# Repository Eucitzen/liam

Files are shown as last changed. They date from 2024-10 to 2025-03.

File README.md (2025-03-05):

# liam - DIY Robot lawn mower

Updates by Eu_citzen 2024-10-10 In development:
- Working (BETA) on a stuck detection function using MPU9150
- Obsticle avoidance using 3 ultrasonic sensors
- Merging several libraries into distinct categories
- Due to increased pin requirements it's being geared towards an STM32 Blackpill module instead of the usual Arduino Uno

Liam is an arduino project for the DIY Robot Lawn Mover.
This program will control your mower and relies on a two coil
configuration (0 and 1) with an optional (2).

The mower is assumed to be rear wheel driven and have three
boundary wire reciever coils in the following configuration

    wheel
    ----------------
    |           (0)|
    |(2)           |  ----> Mowing direction
    |           (1)|
    ----------------
    wheel

Licensed under GNU GPL 3.0

(c) 2017 Jonas Forssell & team

Configuration
------
Most of the default values for your mower can be set in the
Definition.h file. Use this to configure your mower for best
performance.

Configurations can also be put in a file called
`LocalDefinition.h`, which will override `Definition.h` but
is not tracked by git. This might be useful if you like to
stay on top of any code updates, but don't want to remake
the same configuration changes all the time.

Compile
------
The following libraries must be added to your arduino IDE to be able to compile the source

  * HMC5883L
  * I2Cdev
  * LiquidCrystal_I2C
  * MPU9150
  * RTClib
  * RTIMULib

  The libraries you need are bundled with the liam code within each release.

Change log
------
Change log
------
2025-03:
- Further cleaning up library code
- Started working on PCB using STM32F407VET6TR & ESP32 module

2024-12:
- Remade the libraries into relevant categories (e.g. "sensors", "display", "motioncontrol")
- Started removing superflourous libraries for newer Arduino versions
- Cleaning up code for STM32 microcontrollers, found even the STM32 Blackpill has too few pins

2024-11:
- Remade to suite a STM32 Blackpill board, new version needs more pins
- Merged several libraries into distinct categories
- Beta stuck detection using MPU9150
- Added and test printed 3D models for a larger mower

Links
------

[Wiki - work in progress](https://github.com/sm6yvr/liam/wiki)

[Facebook group DIY Robot Lawn Mower](https://www.facebook.com/groups/319588508137220/)

[Build instructions Trello](https://trello.com/b/gYQjoWY5/liam)

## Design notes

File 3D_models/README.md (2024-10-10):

This 3D model is still at a concept stage and is designed around a printer with a 250x250 sized bed.
In other words; the model is intended to be split into 4 equally sized sections.

And "reinforcement_parts.stl" acts as a screw-together support using M4 bolts. Pro tip: use some kind of adhesive, watertight glue inderneat the reinforcement parts!

Note that it works on a 3 wheel basis and you need to print 1 pcs of frontwheel, 2 pcs backwheels.

Typical print settings:
PETG, ABS or Nylon
5 walls, 5 top and bottom layers
50-75% infill (e.g. adaptive cubic or similar strong infill)

Change log:
2024-08-1: Original version was made and test printed
2024-10-10: V2 released
- Sizes for threaded inserts corrected
- Charging "bumper" in the back added for future charging pins OR connector
- Larger bracings/support pieces
- Changed wheel design for extra grip
- Ultrasonic sensor holder changed to not need supports

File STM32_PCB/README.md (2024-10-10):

The PCB is intended to replace the original Liam parts and use an STM32 Blackpill as the brain.
Which gives us more computing power, more pins and options. More over its going to be the goal to largely use parts that allows the user to order a pre-assembled PCB from e.g. JLCPB, PCBway or similar. Thus bringing personal soldering to a minimum.

Changelog:
2024-08-04: Work began

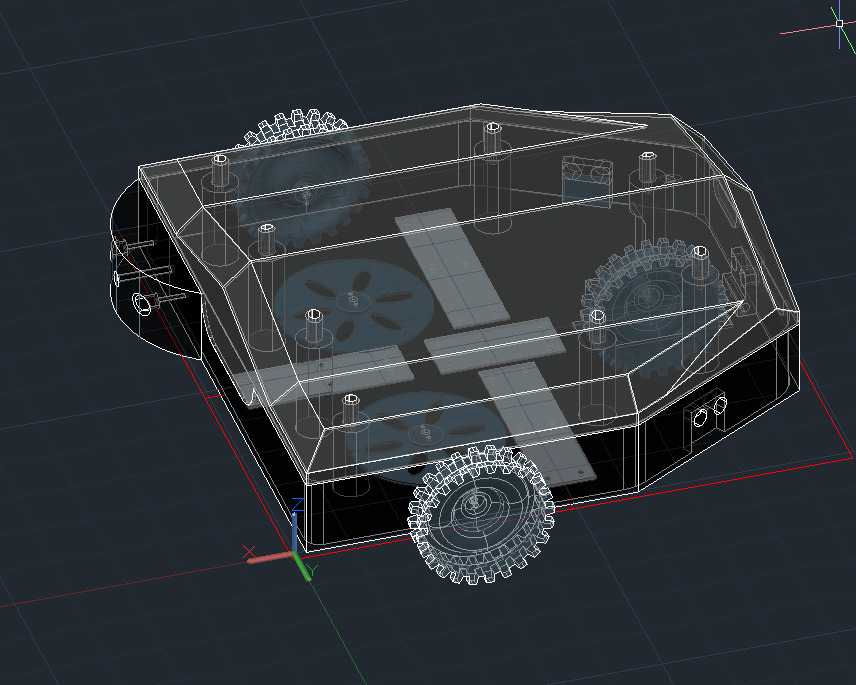
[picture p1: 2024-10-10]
docs/pictures/Liam_STM32_V2.png

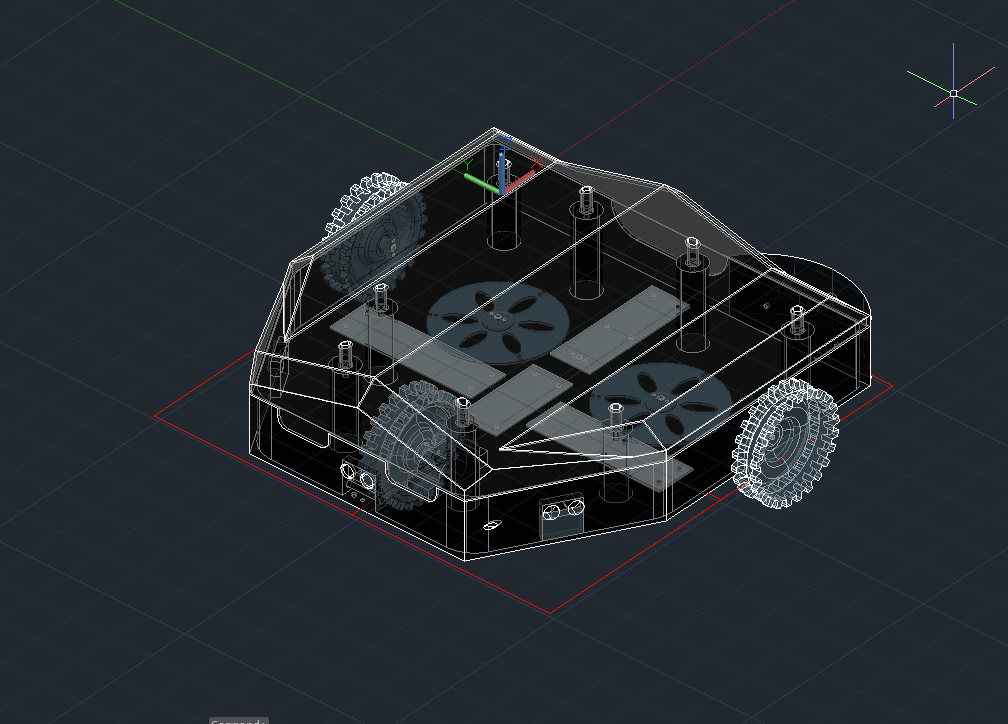
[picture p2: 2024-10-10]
docs/pictures/Liam_STM32Front_V2.png

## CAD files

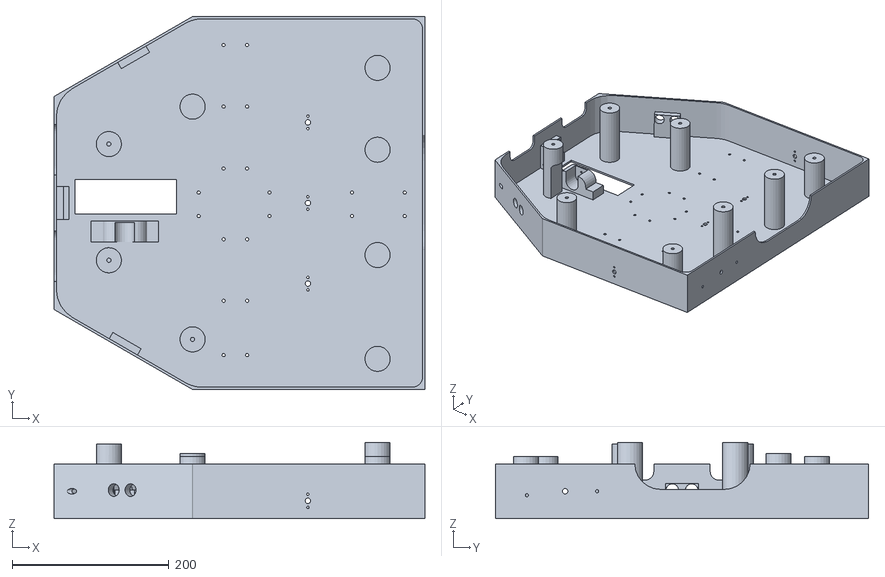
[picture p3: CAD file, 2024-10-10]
3D_models/Base.stl
473.2 x 475.8 x 97.3

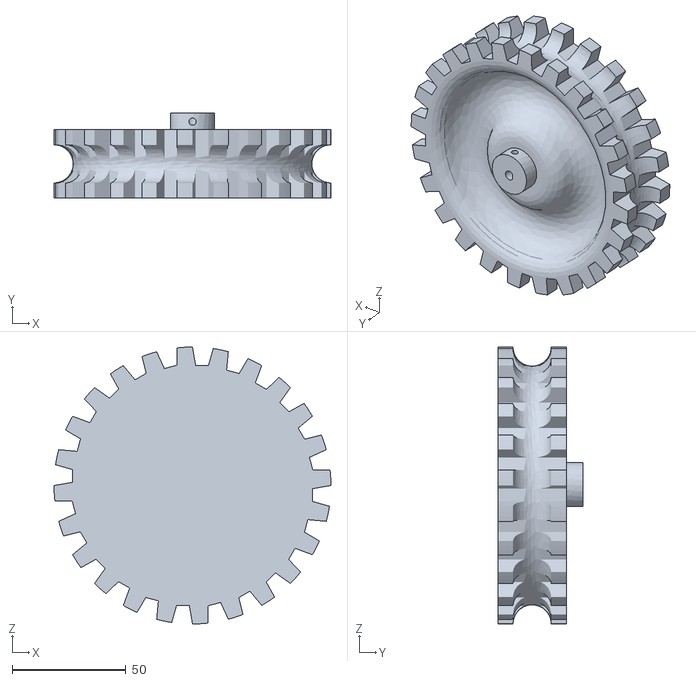
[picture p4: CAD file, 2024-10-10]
3D_models/Back_wheels.stl
122.0 x 37.5 x 122.0

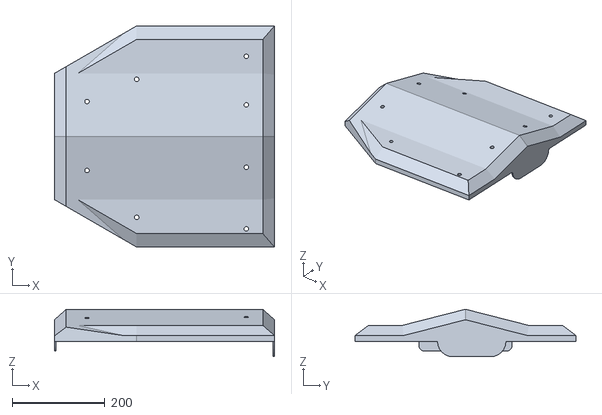
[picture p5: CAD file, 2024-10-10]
3D_models/Top_lid.stl
473.2 x 475.8 x 102.1

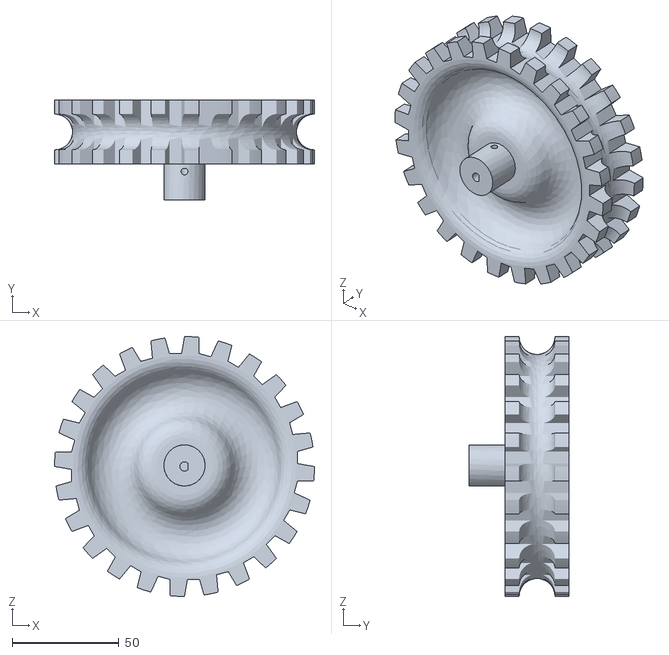
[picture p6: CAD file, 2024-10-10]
3D_models/Front_wheel.stl
122.0 x 47.1 x 122.0

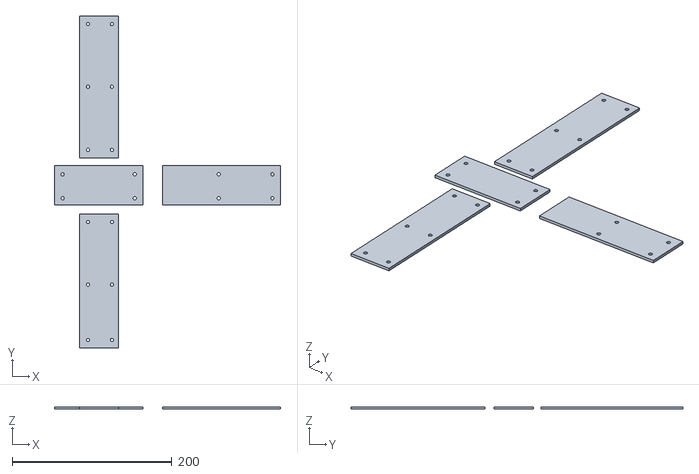
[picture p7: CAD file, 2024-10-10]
3D_models/reinforcement_parts.stl
283.1 x 415.7 x 3.10

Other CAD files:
3D_models/Robot mower.dwg

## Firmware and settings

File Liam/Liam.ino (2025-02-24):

/* 
   Welcome to the Liam5_1 program
   This program will control your mower and relies on a two coil
   configuration (0 and 1) with an optional (2). 
   
   The mower is assumed to be rear wheel driven and have three 
   boundary wire reciever coils in the following configuration
   
   	wheel
    ----------------
   |			(0)	|
   |(2)         	|  ----> Mowing direction
   |			(1)	|
    ----------------
	wheel

	Most of the default values for your mower can be set in the 
	Definition.h file. Use this to configure your mower for best
	performance.

	(c) Jonas Forssell & team
	Free to use for all.
	
	Changes in this version
  - Removed OzOLED Support for Arduino101 Compatibility
  - -----------------------------------------------------------
	- Ultrasound sensor bumper support						(Planned)
	- More robust shutdown of mower if wheel overload		(Planned)
	- Revised Error messages								(Planned)
	- Support for OLED Display								(Planned)
	- Signal sensitivity factor in Definition.h				(Planned)
	- Slower mowing if cutter motor is using much current	(Planned)
	---------------------------------------------------------------
*/

#include <Servo.h>
#include <Wire.h>
#include "Battery.h"
#include "Clock.h"
#include "Error.h"
#include "Motioncontrol.h"
#include "Sensors.h"
#include "Display.h"
#include "Definitions.h"


// Global variables
int state;
long time_at_turning = millis();
int turn_direction = 1;
int LCDi = 0;


// Set up all the defaults (check the Definition.h file for all default values)
DEFINITION Defaults;

// Please select which type of cutter motor you have
// Types available: BRUSHED (for all brushed motors, A3620 and NIDEC 22)
// 					BRUSHLESS (for all hobbyking motors with external ESC)
//					NIDEC (for NIDEC 24)
CUTTERMOTOR CutterMotor(BRUSHED, CUTTER_PWM_PIN, CUTTER_CURRENT_PIN);

// Wheelmotors
WHEELMOTOR rightMotor(WHEEL_MOTOR_A_PWM_PIN, WHEEL_MOTOR_A_DIRECTION_PIN, WHEEL_MOTOR_A_CURRENT_PIN, WHEELMOTOR_SMOOTHNESS);
WHEELMOTOR leftMotor(WHEEL_MOTOR_B_PWM_PIN, WHEEL_MOTOR_B_DIRECTION_PIN, WHEEL_MOTOR_B_CURRENT_PIN, WHEELMOTOR_SMOOTHNESS);

// Battery
// Battery types available are LIION, LEAD_ACID, NIMH
BATTERY Battery(LIION, SOC_PIN, DOCK_PIN);

// BWF Sensors
BWFSENSOR Sensor(BWF_SELECT_B_PIN, BWF_SELECT_A_PIN);

// Compass
#if defined __MS5883L__
	MS5883L Compass;
#elif defined __MS9150__ 
	MS9150 Compass;
#else
	MOTIONSENSOR Compass;
#endif

// Controller (pass adresses to the motors and sensors for the controller to operate on)
CONTROLLER Mower(&leftMotor, &rightMotor, &CutterMotor, &Sensor, &Compass);

// Display
#if defined __LCD__ 
	myLCD Display(&Battery, &leftMotor, &rightMotor, &CutterMotor, &Sensor, &Compass, &state);
#else;
	MYDISPLAY Display(&Battery, &leftMotor, &rightMotor, &CutterMotor, &Sensor, &Compass, &state);
#endif

// RTC klocka
#if defined __RTC_CLOCK__
	CLOCK myClock;
#endif

// Error handler
ERROR Error(&Display, LED_PIN, &Mower);


// ****************** Setup **************************************
void setup()
{
	char buffer [9]; //Format 09.00.00

	Serial.begin(115200); 						// Fast communication on the serial port for all terminal messages

	Defaults.definePinsInputOutput();			// Configure all the pins for input or output
	Defaults.setDefaultLevels(&Battery, &leftMotor, &rightMotor, &CutterMotor); // Set default levels (defined in Definition.h) for your mower

	Display.initialize();							// Start up the display

	CutterMotor.initialize();
	Battery.resetSOC();							// Set the SOC to current value
	Compass.initialize();
	
	#if defined __RTC_CLOCK__
		myClock.initialize();
		myClock.setGoOutTime(GO_OUT_TIME);
		myClock.setGoHomeTime(GO_HOME_TIME);
	#endif

	attachInterrupt(0,updateBWF, RISING);		// Run the updateBWF function every time there is a pulse on digital pin2
	Sensor.select(0);

	if (Battery.isBeingCharged())	{			// If Liam is in docking station then
		state = CHARGING;						// continue charging
		Mower.stopCutter();
	}
	else {										// otherwise
		state = MOWING;							// start mowing
		Mower.startCutter();					// Start up the cutter motor
		Mower.runForward(FULLSPEED);	
	}

}



// ***************** Main loop ***********************************
void loop()
{
	boolean in_contact;
	boolean mower_is_outside;

	LCDi++;  //Loops 0-10
  	if (LCDi % 25 == 0 ){
		Display.update();
  	}
  	
  	// Security check Mower is flipped/lifted.
	#if defined __MS9150__ || defined __MS5883L__
    	if (Mower.hasFlipped())
    	{
    	 	Serial.print("Mower has flipped ");
    	  	Mower.stopCutter();
    	  	Mower.stop();
    	  	Error.flag(9);
		}   
	#endif
	
	#if defined __Lift_Sensor__
		if (Mower.isLifted())
		{
			Serial.println("Mower is lifted");
			Mower.stopCutter();
			Mower.stop();
			delay(500);
			Mower.runBackward(FULLSPEED);
			delay(2000);
   	  		if(Mower.isLifted())
   	  			Error.flag(4);
			Mower.turnRight(90);
			//Mover.startCutter();
   	  		Mower.runForward(FULLSPEED);
   		}
	#endif
  	
  	// Check if stuck and trigger action
  	Mower.updateBalance();

	if (abs(Mower.getBalance()) > BALANCE_TRIGGER_LEVEL) {
		Mower.storeState();
		Mower.runBackward(FULLSPEED);
		delay(1000);
		Mower.stop();
		Mower.restoreState();
		Mower.resetBalance();
		}
	
	switch (state) {
		
		//------------------------- MOWING ---------------------------
		case MOWING:
		
		Battery.updateSOC();
		Display.update();
	
		Sensor.select(0);

		if (BWF_DETECTION_ALWAYS)
			mower_is_outside = !Sensor.isInside();
		else
			mower_is_outside = Sensor.isOutside();

		// Check left sensor (0) and turn right if needed
		if (mower_is_outside) {
			Serial.println("Left outside");
    		Serial.println(Battery.getSOC());
    		Mower.stop();
    		
    		if (Battery.mustCharge()) {
	      		Mower.stopCutter();
	      		Mower.runForward(FULLSPEED);
	      		delay(1000);
	      		Mower.stop();
	      		Sensor.select(0);
       			state = DOCKING;
       			break;
    		}
    		
    		// Tries to turn, but if timeout then reverse and try again
			if (int err = Mower.turnToReleaseRight(30) > 0) {
				Mower.runBackward(FULLSPEED);
				delay(1000);
				Mower.stop();
				if (int err = Mower.turnToReleaseRight(30) > 0)
					Error.flag(err);
				}
			
			Compass.setNewTargetHeading();

    		if (Mower.allSensorsAreOutside()) { 
				Mower.runBackward(FULLSPEED);
				delay(1000);
				Mower.stop();
				if (Mower.allSensorsAreOutside())
    				Error.flag(4);
    		}
		}
		
		Sensor.select(1);

		if (BWF_DETECTION_ALWAYS)
			mower_is_outside = !Sensor.isInside();
		else
			mower_is_outside = Sensor.isOutside();
		
		// Check right sensor (1) and turn left if needed		
		if (mower_is_outside) {
			Serial.println("Right Outside");
			Serial.println(Battery.getSOC());
    		Mower.stop();

    		// Tries to turn, but if timeout then reverse and try again
			if (int err = Mower.turnToReleaseLeft(30) > 0) {
				Mower.runBackward(FULLSPEED);
				delay(1000);
				Mower.stop();
				if (int err = Mower.turnToReleaseLeft(30) > 0)
					Error.flag(err);
				}
				
			Compass.setNewTargetHeading();

    		if (Mower.allSensorsAreOutside()) { 
				Mower.runBackward(FULLSPEED);
				delay(1000);
				Mower.stop();
				if (Mower.allSensorsAreOutside())
    				Error.flag(4);
    		}
		}

	
		Mower.runForward(FULLSPEED);

		// Adjust the speed of the mower to the grass thickness
 		Mower.compensateSpeedToCutterLoad();

    	// Adjust the speed of the mower to the compass heading
   		Compass.updateHeading();
		Mower.compensateSpeedToCompassHeading();        


    	// Check if mower has hit something
    	if (Mower.wheelsAreOverloaded())
    	{
    	 	Serial.print("Wheel overload ");
    	  	Mower.runBackward(FULLSPEED);
    	  	if(Mower.waitWhileInside(2000) == 0);
    	  		Mower.turnRight(90);
    	  	Compass.setNewTargetHeading();
    	  	Mower.runForward(FULLSPEED);
		}   

		// Check if bumper has triggered (providing you have one enabled)
		#if defined __Bumper__
    		if (Mower.hasBumped())
    		{
    	 		Serial.print("Mower has bumped ");
    	  		Mower.runBackward(FULLSPEED);
    	  		delay(2000);
    	  		Mower.turnRight(90);
    	  		Mower.runForward(FULLSPEED);
			}   
		#endif

		// Use distance sensor HC-SR04 to avoid collision
		#if defined __SR04__
		 avoidObstacles robot(trigPinLeft, echoPinLeft, trigPinRight, echoPinRight, trigPinFront, echoPinFront);
		 robot.avoidObstacles();
	#endif

}
		 }

		#if defined __Lift_Sensor__
			if (Mower.isLifted())
			{
				Serial.println("Mower is lifted");
				Mower.stopCutter();
				Mower.runBackward(FULLSPEED);
				delay(2000);
    	  		if(Mower.isLifted())
    	  			Error.flag(4);
				Mower.turnRight(90);
    	  		Mower.startCutter();
    	  		Mower.runForward(FULLSPEED);
			}
		#endif

		// Check if mower has tilted (providing you have one enabled)
		#if defined __MS9150__ || defined __MS5883L__
    		if (Mower.hasTilted())
    		{
    	 		Serial.print("Mower has tilted ");
    	  		Mower.runBackward(FULLSPEED);
    	  		delay(2000);
    	  		Mower.turnRight(90);
    	  		Mower.runForward(FULLSPEED);
    	  		delay(200);
			}   

		// Check if mower has flipped (providing you have one enabled)
    		if (Mower.hasFlipped())
    		{
    	 		Serial.print("Mower has flipped ");
    	  		Mower.stopCutter();
    	  		Mower.stop();
    	  		Error.flag(9);
			}   
		#endif


		break;


		//----------------------- LAUNCHING ---------------------------
		case LAUNCHING:

    	Mower.runBackward(FULLSPEED);

    	delay(7000);
    	Mower.stop();

    	// Turn right in random degree
    	Mower.turnRight(random(30,60));
    	Mower.startCutter();
    	Mower.waitWhileChecking(5000);      

      	Compass.setNewTargetHeading();

    	Mower.runForward(FULLSPEED);

    	state = MOWING;

    	// Reset the running average
    	Battery.resetSOC();  

		break;

		//----------------------- DOCKING -----------------------------
		case DOCKING:

			//Make the wheel motors extra responsive
			leftMotor.setSmoothness(10);
			rightMotor.setSmoothness(10);

			// If the mower hits something, reverse and try again
			if (Mower.wheelsAreOverloaded()){
				Mower.runBackward(FULLSPEED);
				delay(1000);
			}

			// Track the BWF by compensating the wheel motor speeds
			Mower.adjustMotorSpeeds();
			
			// Clear signal to allow the mower to track the wire closely
			Sensor.clearSignal();
			
			// Wait a little to avoid current spikes
			delay(100);
			
			// Stop the mower as soon as the charge plates come in contact
			if (Battery.isBeingCharged()) {
				// Stop
				Mower.stop();
				Mower.resetBalance();
				state = CHARGING;
				break;
			}


		break;

		//----------------------- CHARGING ----------------------------
		case CHARGING:
		// restore wheelmotor smoothness
		leftMotor.setSmoothness(WHEELMOTOR_SMOOTHNESS);
		rightMotor.setSmoothness(WHEELMOTOR_SMOOTHNESS);

		// Just remain in this state until battery is full
		#if defined __RTC_CLOCK__
			if (Battery.isFullyCharged() && myClock.timeToCut()) 
			state = LAUNCHING;
		#else
			if (Battery.isFullyCharged()) 
			state = LAUNCHING;
		#endif
		
		in_contact = false;
		
		// Spend 20 seconds collecting status if being charged
		for (int i=0; i<20; i++) {
			if (Battery.isBeingCharged())
				in_contact = true;
			delay(1000);
		}
		
		// If the mower is not being charged, jiggle it a bit
		if (!in_contact) { 
			Mower.runBackward(20); 	// Back away slow speed 
			delay(500);
			Mower.runForward(20);	// Dock again at slow speed
			delay(1000);
			Mower.stop();
		}

	 	Serial.print("SOC:");
		Serial.println(Battery.getSOC());

		break;

	}
}

// This function calls the sensor object every time there is a new signal pulse on pin2
void updateBWF() {
	Sensor.readSensor();
}

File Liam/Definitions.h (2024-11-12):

// This is for a STM32 Blackpill F401CC board as the new functonality needs more pins than an arduino uno offers

#ifndef _DEFINITION_H_
#define _DEFINITION_H_
#include "Battery.h"
#include "Motioncontrol.h"

const int NUMBER_OF_SENSORS = 3;  // Number of BWF sensors can be 1-4 depending on shield

// Pin setup following Morgan 1.5 shield and up
// Motor A; left
// Motor B; B backwheel, right
// Motor C; front or front left
#define WHEEL_MOTOR_A_CURRENT_PIN B1  //ADC pins
#define WHEEL_MOTOR_B_CURRENT_PIN B0  // ADC Pins
#define WHEEL_MOTOR_C_CURRENT_PIN
#define SOC_PIN A5                    //ADC
#define CUTTER_CURRENT_PIN A4         //ADC
#define I2C_SDA_PIN B9
#define I2C_SDL_PIN B8  // Done
// Digital pins
#define RX_PIN A10
#define TX_PIN A9
#define BWF_SENSOR_INPUT_PIN 2
#define BWF_SELECT_A_PIN  A12
#define BWF_SELECT_B_PIN  A11
#define DOCK_PIN A8
#define CUTTER_PWM_PIN A7
//#define BUMPER							8   Obselete
#define LIFT_SENSOR_PIN  B12
#define LED_PIN PC13
#define WHEEL_MOTOR_A_PWM_PIN A1
#define WHEEL_MOTOR_A_DIRECTION_PIN  B13
#define WHEEL_MOTOR_B_PWM_PIN A0
#define WHEEL_MOTOR_B_DIRECTION_PIN B10
#define WHEEL_MOTOR_C_PWM_PIN A1
#define WHEEL_MOTOR_C_DIRECTION_PIN  B13
// Ultrasonic pins
#define trigPinLeft B7
#define echoPinLeft B6
#define trigPinRight B5
#define echoPinRight B4
#define trigPinFront B3
#define echoPinFront A15


// Cutter motor types
//#define BRUSHLESS						0
#define BRUSHED 1
//#define NIDEC							2

// Battery type
#define LEADACID 0
#define NIMH 1
#define LIION 2

// Wheel motor
#define WHEELMOTOR_OVERLOAD 130
#define WHEELMOTOR_SMOOTHNESS 300

// CUTTER
#define CUTTER_OVERLOAD 100

// Cutter states
const int MOWING = 0;
const int LAUNCHING = 1;
const int DOCKING = 2;
const int CHARGING = 3;

// Turning details
#define TURN_INTERVAL 15000
#define REVERSE_DELAY 2
#define TURNDELAY 20  //Reduce for smaller turning angle

// BWF Detection method (true = always, false = only at wire)
#define BWF_DETECTION_ALWAYS true
#define TIMEOUT 6000  //Time without signal before error

// Trigger value for the mower to leave the BWF when going home
// The higher value the more turns (in the same direction) the mower can make before leaving
#define BALANCE_TRIGGER_LEVEL 10000

// Code for inside and outside
//#define INSIDE_BWF						103,4,103
//#define OUTSIDE_BWF						103,107,103

// Version 2 of the BWF transmitter
#define INSIDE_BWF 85
#define OUTSIDE_BWF 5

#define MAJOR_VERSION 4
#define MINOR_VERSION_1 9
#define MINOR_VERSION_2 1

// Obsticle avoidance

// If you have a bumper connected to pin8, uncomment the line below. Remember to cut the brake connection on your motor shield
//#define __Bumper__

// If you have 3 ultrasonic sensors of HC-SR04 uncomment the line below
#define __SR04__

// If you have a lift sensor connection to front wheel (connected to pin9), uncomment this line
//#define __Lift_Sensor__

// Do you have a Sensor? If so, uncomment one of these lines
//#define __MS5883L__
#define __MS9150__

#define __MS9150motion__ // enables the beta function of using MS9150 for detecting if robot is stuck
#define __averaging__  //Averages the values of the MPU-9150 for stability when using stuck detection

// Do you have a Display? If so, uncomment one of these lines
//#define __OLED__
//#define __LCD__

// Do you have a clock? If so, uncomment the line below
#define __RTC_CLOCK__
#define GO_OUT_TIME 16, 00
#define GO_HOME_TIME 22, 00

// Tiltangle
#define TILTANGLE 45

// Flipangle (turn off cutter and stop everything)
#define FLIPANGLE 75

// Motor Speeds
#define FULLSPEED 100
#define SLOWSPEED 30
#define CUTTERSPEED 100

class DEFINITION {
public:
  void definePinsInputOutput();
  void setDefaultLevels(BATTERY* battery, WHEELMOTOR* left, WHEELMOTOR* front, WHEELMOTOR* right, CUTTERMOTOR* cutter);

private:

};
#endif /* _DEFINITION_H_ */

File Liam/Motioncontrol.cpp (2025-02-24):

/* This is the library for motor control and obsticle avoidance

 Changelog:
    2014-12-12 - Initial version by Jonas
    2024-10-13 - Remodeled by Willie
*/
/* ============================================
Placed under the GNU license

===============================================
*/


#include "Motioncontrol.h"
#include "Definitions.h"

/** Wheelmotor controller. */

CONTROLLER::Wheelmotor(Wheelmotor& left, Wheelmotor& right, Wheelmotor& front, Boundarysens& bwf, Motionsens& comp):
    leftMotor(left),
    rightMotor(right),
	frontMotor(front),
    cutter(cut),
    sensor(bwf),
    compass(comp)
{
    default_dir_fwd = 1;
    balance = 0;
}

boolean CONTROLLER::allSensorsAreOutside() {
	
	for(int i=0; i<NUMBER_OF_SENSORS; i++) {
		sensor.select(i);
		if (!sensor.isOutside())
			return false;
	}

	return true;	
}

int CONTROLLER::turnToReleaseLeft(int angle) {
	turnLeft(angle);
	
	for (int i=0; i<20; i++) {
		sensor.select(1);

		if (sensor.isInside()) {
			sensor.select(0);
			if (sensor.isInside())
				return 0;				// OK
		}
		
		if (wheelsAreOverloaded())
			return 1;					// Overloaded
		
		turnLeft(10);
	}
	
	return 2;							// Timed Out
}

int CONTROLLER::turnToReleaseRight(int angle) {
	turnRight(angle);
	
	for (int i=0; i<20; i++) {
		sensor.select(0);

		if (sensor.isInside()) {
			sensor.select(1);
			if (sensor.isInside())
				return 0;				// OK
		}
		
		if (wheelsAreOverloaded())
			return 1;					// Overloaded
		
		turnRight(10);
	}
	
	return 2;							// Timed Out
}

int CONTROLLER::turnRight(int angle) {
	int outcome = 0;
	
	leftMotor.setSpeed(default_dir_fwd*100);
	rightMotor.setSpeed(default_dir_fwd*-100);
	frontMotor.setSpeed(default_dir_fwd*100)
	
	delay(angle*TURNDELAY);

    return outcome;
}


int CONTROLLER::turnLeft(int angle) {
	int outcome = 0;
	
	leftMotor.setSpeed(default_dir_fwd*-100);
	rightMotor.setSpeed(default_dir_fwd*100);
	frontMotor.setSpeed(default_dir_fwd*100)
	
	delay(angle*TURNDELAY);

    return outcome;
}

int CONTROLLER::waitWhileChecking(int duration) {
  
  delay(200);   // Let any current spikes settle

  for (int i=0; i<duration/30; i++) {
    // check for problems
    if(leftMotor.isOverloaded()) 
      return 2;
    if(rightMotor.isOverloaded())
      return 2;
	if(frontMotor.isOverloaded())
	 return 2;
    if (sensor.isTimedOut())
      return 3;
    
    delay(turnDelay); 
    }

	// Successful delay
	return 0;
}

int CONTROLLER::waitWhileInside(int duration) {
  
  for (int k=0; k<duration/(NUMBER_OF_SENSORS*200); k++)
  	for (int i=0; i<NUMBER_OF_SENSORS; i++) {
    	sensor.select(i);
    	if(!sensor.isInside()) 
      		return 2;
  	}
  
  // Successful delay
  return 0;      
}

void CONTROLLER::startCutter() {
	for (int i=0; i<CUTTERSPEED; i++) 
		cutter.setSpeed(i);
}

void CONTROLLER::stopCutter() {
	cutter.setSpeed(0);
}

void CONTROLLER::storeState() {
	leftMotorSpeed = leftMotor.getSpeed();
	rightMotorSpeed = rightMotor.getSpeed();
	frontMotorSpeed = frontMotor.getSpeed();
	cutterSpeed = cutter.getSpeed();
}

void CONTROLLER::restoreState() {
	leftMotor.setSpeed(leftMotorSpeed);
	rightMotor.setSpeed(rightMotorSpeed);
	frontMotor.setSpeed(frontMotorSpeed);
	cutter.setSpeed(cutterSpeed);
}

void CONTROLLER::runForward(int speed) {
	leftMotor.setSpeed(default_dir_fwd*speed);
	rightMotor.setSpeed(default_dir_fwd*speed);
	frontMotor.setSpeed(default_dir_fwd*speed);
}

void CONTROLLER::runBackward(int speed) {
	leftMotor.setSpeed(default_dir_fwd*-speed);
	rightMotor.setSpeed(default_dir_fwd*-speed);
	frontMotor.setSpeed(default_dir_fwd-speed);
}

void CONTROLLER::setDefaultDirectionForward(bool fwd) {
	if (fwd == true)
		default_dir_fwd = 1;
	else
		default_dir_fwd = -1;
};

void CONTROLLER::adjustMotorSpeeds(); {
  int  lms = abs(leftMotor.getSpeed());
  int  rms = abs(rightMotor.getSpeed());
  int  fms = abs(frontMotor.getSpeed());


  if (!sensor.isInside()) {
  	lms = 100;
  	rms = 10;
	fms = 10;
  }
  else 
  if (sensor.isInside())
  {
	lms = 10;
	rms = 100;
	fms = 10
  }
  else {
    rms += 80;
    lms += 80;
	fms +=80;
  }

  if (rms > 100) rms = 100;
  if (lms > 100) lms = 100;
  if (fms > 100) fms = 100;
  if (rms < -50) rms = -50;
  if (lms < -50) lms = -50;
  if (fms < -50) fms = -50;
  leftMotor.setSpeed(default_dir_fwd*lms);
  rightMotor.setSpeed(default_dir_fwd*rms);
}

void CONTROLLER::updateBalance() {
	balance = balance + leftMotor.getSpeed() - rightMotor.getSpeed();
	
	if(balance > 0)
		balance-=10;
	else
		balance+=10;
}



void CONTROLLER::stop() {
	leftMotor.setSpeed(0);
	rightMotor.setSpeed(0);
	frontMotor.setSpeed(0);

}

int CONTROLLER::compensateSpeedToCutterLoad() {
	
}

int CONTROLLER::compensateSpeedToCompassHeading() {
	int  lms = abs(leftMotor.getSpeed());
	int  rms = abs(rightMotor.getSpeed());
	int  fms = abs(frontMotor.getSpeed());

    if (compass.headingVsTarget() < 0) {
    	rms = 0.9*rms;
        }
    else if (compass.headingVsTarget() > 0) {
        lms = 0.9*lms;
        }

	leftMotor.setSpeed(default_dir_fwd*lms);
	rightMotor.setSpeed(default_dir_fwd*rms);
    frontMotor.setSpeed(default_dir_fwd*fms);
}

olean CONTROLLER::wheelsAreOverloaded() {
	delay(200);				// Settle current spikes
	if (leftMotor.isOverloaded() | rightMotor.isOverloaded | frontMotor.isOverloaded())
		return true;
	else
		return false;

boolean CONTROLLER::hasBumped() {
	return !digitalRead(BUMPER);
}

boolean CONTROLLER::hasTilted() {
	return (compass.getTiltAngle() > TILTANGLE);
}

boolean CONTROLLER::hasFlipped() {
	return (compass.getTiltAngle() > FLIPANGLE);
}

boolean CONTROLLER::isLifted() {
	return !digitalRead(LIFT_SENSOR_PIN);
}

void CONTROLLER::resetBalance() {
	balance = 0;
}

int CONTROLLER::getBalance() {
	return balance;
}

int CONTROLLER::avoidObstacles(int trigPinLeft, int echoPinLeft, int trigPinRight, int echoPinRight, int trigPinFront, int echoPinFront) {
    _trigPinLeft = trigPinLeft;
    _echoPinLeft = echoPinLeft;
    _trigPinRight = trigPinRight;
    _echoPinRight = echoPinRight;
    _trigPinFront = trigPinFront;
    _echoPinFront = echoPinFront;
}

long avoidObstacles::getDistance(int trigPin, int echoPin) {
    digitalWrite(trigPin, LOW);
    delayMicroseconds(2);
    digitalWrite(trigPin, HIGH);
    delayMicroseconds(10);
    digitalWrite(trigPin, LOW);
    long duration = pulseIn(echoPin, HIGH);
    return duration * 0.034 / 2;
}

void avoidObstacles::avoidObstacles() {
    long distanceFront = getDistance(_trigPinFront, _echoPinFront);
    long distanceLeft = getDistance(_trigPinLeft, _echoPinLeft);
    long distanceRight = getDistance(_trigPinRight, _echoPinRight);
    
    if (distanceFront < 5) {
        Mower.stop();
		millis(200);
        if (distanceLeft > distanceRight) {
            turnLeft();
        } 
        if(distanceleft < distanceRight) {
            turnRight();
        }
        if(distanceFront < 5){
        millis(500);
        if(distanceFront < 5)
        turnRight();    
        }
    } else {
        Mower.runForward(FULLSPEED);
    }
}
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

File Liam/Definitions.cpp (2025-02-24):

/// This is the library for the defaults
//
// Changelog:

//     2014-12-12 - Initial version by Jonas
//     2024-10-13 - Added ultrasonic support by Willie
//     2025-02-12 correcting pins and expanding pin definitions for larger chip

/* ============================================
Placed under the GNU license

===============================================
*/

#include "Definitions.h"
#include "Motioncontrol.h"




/** Define all pins */
void DEFINITION::definePinsInputOutput() {
/* These are no longer in use due to built-in current protection*/
  //pinMode(WHEEL_MOTOR_A_CURRENT_PIN, INPUT);
  //pinMode(WHEEL_MOTOR_B_CURRENT_PIN, INPUT);
  //pinMode(CUTTER_CURRENT_PIN, INPUT);

  pinMode(SOC_PIN, INPUT); //State of charge for reading battery
  

  /*
    Some pins are better leave undefined as default
	pinMode(I2C_SDA_PIN, INPUT);
	pinMode(I2C_SDL_PIN, OUTPUT);

	pinMode(RX_PIN, INPUT);	
	pinMode(TX_PIN, OUTPUT);
  */
  pinMode(BWF_SENSOR_INPUT_PIN, INPUT);
  pinMode(WHEEL_MOTOR_A_PWM_PIN, OUTPUT);
  pinMode(BWF_SELECT_A_PIN, OUTPUT);
  pinMode(DOCK_PIN, INPUT);
  pinMode(CUTTER_PWM_PIN, OUTPUT);
  pinMode(BWF_SELECT_B_PIN, OUTPUT);

#if defined __Bumper__
  pinMode(BUMPERfront, INPUT);
  pinMode(BUMPERleft, INPUT);
  pinMode(BUMPERright, INPUT);
  digitalWrite(BUMPERfront, HIGH);
  digitalWrite(BUMPERleft, HIGH);
  digitalWrite(BUMPERright, HIGH);
#else
  pinMode(BUMPERfront, OUTPUT);
  pinMode(BUMPERleft, OUTPUT);
  pinMode(BUMPERright, OUTPUT);
  digitalWrite(BUMPERfront, LOW);
  digitalWrite(BUMPERleft, LOW);
  digitalWrite(BUMPERright, LOW);
#endif

#if defined __SR04__
  pinMode(_trigPinLeft, OUTPUT);
  pinMode(_echoPinLeft, INPUT);
  pinMode(_trigPinRight, OUTPUT);
  pinMode(_echoPinRight, INPUT);
  pinMode(_trigPinFront, OUTPUT);
  pinMode(_echoPinFront, INPUT);
#endif

#if defined __Lift_Sensor__
  pinMode(LIFT_SENSOR_PIN, INPUT);
  digitalWrite(LIFT_SENSOR_PIN, HIGH);
#else
  pinMode(LIFT_SENSOR_PIN, OUTPUT);
  digitalWrite(LIFT_SENSOR_PIN, LOW);
#endif
  pinMode(LED_PIN, OUTPUT);
  pinMode(WHEEL_MOTOR_B_PWM_PIN, OUTPUT);
  pinMode(WHEEL_MOTOR_A_DIRECTION_PIN, OUTPUT);
  pinMode(WHEEL_MOTOR_B_DIRECTION_PIN, OUTPUT);
}

/*void DEFINITION::setDefaultLevels(BATTERY& battery, WHEELMOTOR& left, WHEELMOTOR& front, WHEELMOTOR& right, CUTTERMOTOR& cutter) {
  left->setOverloadLevel(WHEELMOTOR_OVERLOAD);
  right->setOverloadLevel(WHEELMOTOR_OVERLOAD);
  cutter->setOverloadLevel(CUTTER_OVERLOAD);
}*/

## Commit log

2024-10-10 Complete revamp
    - Remade to suite a STM32 Blackpill board, new version needs more pins
    - Merged several libraries into distinct categories
    - Beta stuck detection using MPU9150
    [Liam.ino, MyDisplay.cpp]
2024-10-10 Update README.md
    Explanation of whats going on and elaborate on current projects goals and work.
2024-10-10 Added 3d models and PCB for future
    Adding basic aspects for future developments.
    [Back_wheels.stl, Base.stl, Front_wheel.stl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]
2025-02-24 PCB progress & coding
    Removed superflourous libraries for STM32 and newer arduino versions.
    Backing up PCB schematic progress.
    [Liam_PCB.kicad_pcb, Liam_PCB.kicad_sch, MCU_POWER.kicad_sch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]
